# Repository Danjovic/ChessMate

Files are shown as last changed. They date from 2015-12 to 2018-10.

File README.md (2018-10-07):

# ChessMate

The ChessMate is an AVR ATmega328P running at 25 MHz with chess Engine based on recursive negamax search micro-Max 4.8 by [H.G. Muller]
The hash table was removed by [Andre Adrian].

Our contribution are the following features:
- Included [Threefold repetition rule] using Compact Chess Representation of history boards ([C.C.R.]), we made it valid 
for the last 15 boards with 32 bytes per board; so the history boards occupies 480 bytes of RAM.
- Included the [Fifty-move rule] check from [fairy-Max].

Processing Speed:
For instance, the 32-bit test version of Rybka on AMD 64-bit CPU running on 2.4Ghz achieves 104 Knps (thousands of nodes 
per second); refer to [C.C.R.].

The ATmega328P ChessMate at 25 MHz approach, can reach ~1.3 Knps (1298.1 nodes/s).

A node refers to a branch of play the computer investigated. 

[H.G. Muller]: <http://home.hccnet.nl/h.g.muller/max-src2.html>
[Andre Adrian]: <http://www.andreadrian.de/schach/#Selbstbau_Schachcomputer_SHAH>
[C.C.R.]: <http://www.doiserbia.nb.rs/img/doi/0354-0243/2012/0354-02431200011V.pdf>
[fairy-Max]: <http://home.hccnet.nl/h.g.muller/CVfairy.html>
[Demo Video]: <https://youtu.be/5uhqcVmfm20>
[Hackaday Entry]: <https://hackaday.io/project/8705-chess-mate>
[Threefold repetition rule]: <https://en.wikipedia.org/wiki/Threefold_repetition>
[Fifty-move rule]: <https://en.wikipedia.org/wiki/Fifty-move_rule>

> First release at 15-Feb-2016

How to play:
Initially, it should appear "PLAY" at the display
- Press and hold "NEW" + the number of level
- Enter your 4 digit move then press "ENTER"
- Wait for lily thinking (it will be displayed blinking dots)
- The lily move will be displayed just after the thinking
- If you entered an erroneous digit; press "CLR", short press, to delete one digit
- If you want to delete all digits entered, press and hold "CLR"

See the [Demo Video] and the [Hackaday Entry]

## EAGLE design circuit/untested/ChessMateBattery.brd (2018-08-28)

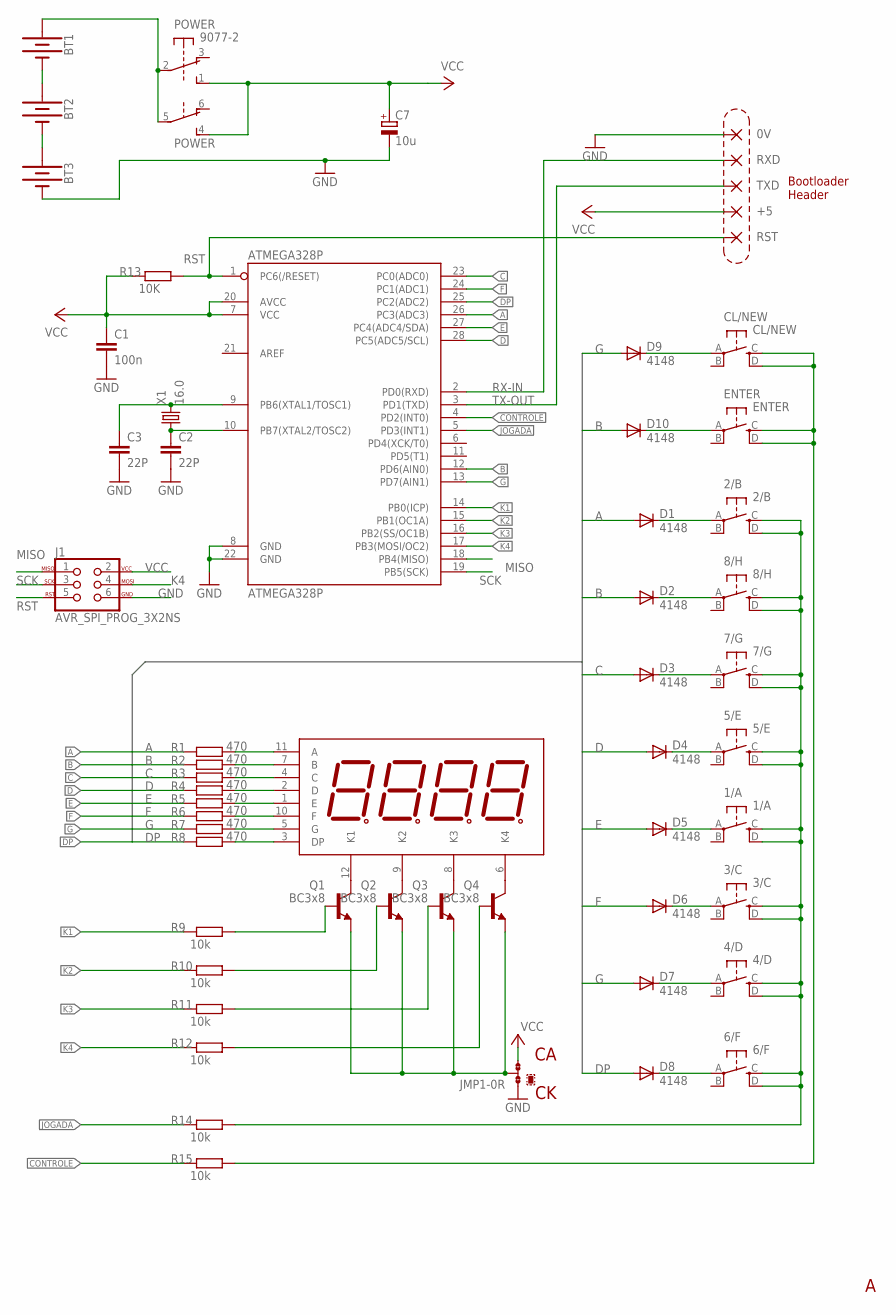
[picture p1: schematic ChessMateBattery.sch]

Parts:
0V: 2,15/1,0
1/A: 1/A; TACT_SW
2/B: 2/B; TACT_SW
3/C: 3/C; TACT_SW
4/D: 4/D; TACT_SW
5/E: 5/E; TACT_SW
6/F: 6/F; TACT_SW
7/G: 7/G; TACT_SW
8/H: 8/H; TACT_SW
+5: 2,15/1,0
ATMEGA328P: ATMEGA328P; DIL28-3
BT1, BT2, BT3: BATTERY-AAA_KIT; BATTERY-AAA-KIT
C1: 100n; C050-024X044L
C2, C3: 22P; C025-024X044L
C7: 10u; TT2D7L
CL/NEW: CL/NEW; TACT_SW
D1, D2, D3, D4, D5, D6, D7, D8, D9, D10: 4148; DO35-7
DISPLAY: 4_DIGIT-TOF3461BH-N; TOF3461BH-N
ENTER: ENTER; TACT_SW
J1: AVR_SPI_PROG_3X2NS; 2X3-NS
JMP1: 0R-JUMPA; A0R-JMP
POWER: 9077-2
Q1, Q2, Q3, Q4: BC3x8; TO92-EBC
R1, R2, R3, R4, R5, R6, R7, R8: 470; 0204/7L
R9, R10, R11, R12, R14, R15: 10k; 0204/7L
R13: 10K; 0204/5L
RST: 2,15/1,0
RXD: 2,15/1,0
TXD: 2,15/1,0
X1: 16.0; HC49/SL

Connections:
A: ATMEGA328P.26 (PC3(ADC3)), D1.A, R1.1
B: ATMEGA328P.12 (PD6(AIN0)), D2.A, D10.A, R2.1
C: ATMEGA328P.23 (PC0(ADC0)), D3.A, R3.1
CONTROLE: ATMEGA328P.4 (PD2(INT0)), R15.1
CONTROLE_: CL/NEW.C (S), CL/NEW.D (S1), ENTER.C (S), ENTER.D (S1), R15.2
D: ATMEGA328P.28 (PC5(ADC5/SCL)), D4.A, R4.1
DP: ATMEGA328P.25 (PC2(ADC2)), D8.A, R8.1
E: ATMEGA328P.27 (PC4(ADC4/SDA)), D5.A, R5.1
F: ATMEGA328P.24 (PC1(ADC1)), D6.A, R6.1
G: ATMEGA328P.13 (PD7(AIN1)), D7.A, D9.A, R7.1
GND: 0V.1, ATMEGA328P.8 (GND), ATMEGA328P.22 (GND), BT3.GND@1 (-), C1.2, C2.2, C3.2, C7.-, J1.6, JMP1.1
JOGADA: ATMEGA328P.5 (PD3(INT1)), R14.1
JOGADA_C: 1/A.C (S), 1/A.D (S1), 2/B.C (S), 2/B.D (S1), 3/C.C (S), 3/C.D (S1), 4/D.C (S), 4/D.D (S1), 5/E.C (S), 5/E.D (S1), 6/F.C (S), 6/F.D (S1), 7/G.C (S), 7/G.D (S1), 8/H.C (S), 8/H.D (S1), R14.2
K1: ATMEGA328P.14 (PB0(ICP)), R9.1
K2: ATMEGA328P.15 (PB1(OC1A)), R10.1
K3: ATMEGA328P.16 (PB2(SS/OC1B)), R11.1
K4: ATMEGA328P.17 (PB3(MOSI/OC2)), J1.4, R12.1
MISO: ATMEGA328P.18 (PB4(MISO)), J1.1
unnamed: DISPLAY.11 (A), R1.2
unnamed: DISPLAY.7 (B), R2.2
unnamed: DISPLAY.4 (C), R3.2
unnamed: DISPLAY.2 (D), R4.2
unnamed: DISPLAY.1 (E), R5.2
unnamed: DISPLAY.10 (F), R6.2
unnamed: DISPLAY.5 (G), R7.2
unnamed: DISPLAY.3 (DP), R8.2
unnamed: Q1.B, R9.2
unnamed: Q2.B, R10.2
unnamed: Q3.B, R11.2
unnamed: Q4.B, R12.2
unnamed: DISPLAY.12 (K1), Q1.C
unnamed: DISPLAY.9 (K2), Q2.C
unnamed: DISPLAY.8 (K3), Q3.C
unnamed: DISPLAY.6 (K4), Q4.C
unnamed: ATMEGA328P.9 (PB6(XTAL1/TOSC1)), C3.1, X1.2
unnamed: ATMEGA328P.10 (PB7(XTAL2/TOSC2)), C2.1, X1.1
unnamed: BT1.PWR@1 (+), POWER.2, POWER.5
unnamed: CL/NEW.A, D9.C
unnamed: D10.C, ENTER.A
unnamed: 2/B.A, D1.C
unnamed: 8/H.A, D2.C
unnamed: 5/E.A, D4.C
unnamed: 1/A.A, D5.C
unnamed: 3/C.A, D6.C
unnamed: 4/D.A, D7.C
unnamed: 6/F.A, D8.C
unnamed: 7/G.A, D3.C
unnamed: BT1.GND@1 (-), BT2.PWR@1 (+)
unnamed: BT2.GND@1 (-), BT3.PWR@1 (+)
unnamed: JMP1.2, Q1.E, Q2.E, Q3.E, Q4.E
RST: ATMEGA328P.1 (PC6(/RESET)), J1.5, R13.2, RST.1
RX-IN: ATMEGA328P.2 (PD0(RXD)), RXD.1
SCK: ATMEGA328P.19 (PB5(SCK)), J1.3
TX-OUT: ATMEGA328P.3 (PD1(TXD)), TXD.1
VCC: +5.1, ATMEGA328P.7 (VCC), ATMEGA328P.20 (AVCC), C1.1, C7.+, J1.2, JMP1.3, POWER.1 (S), POWER.4 (S), R13.1

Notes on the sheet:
Bootloader Header

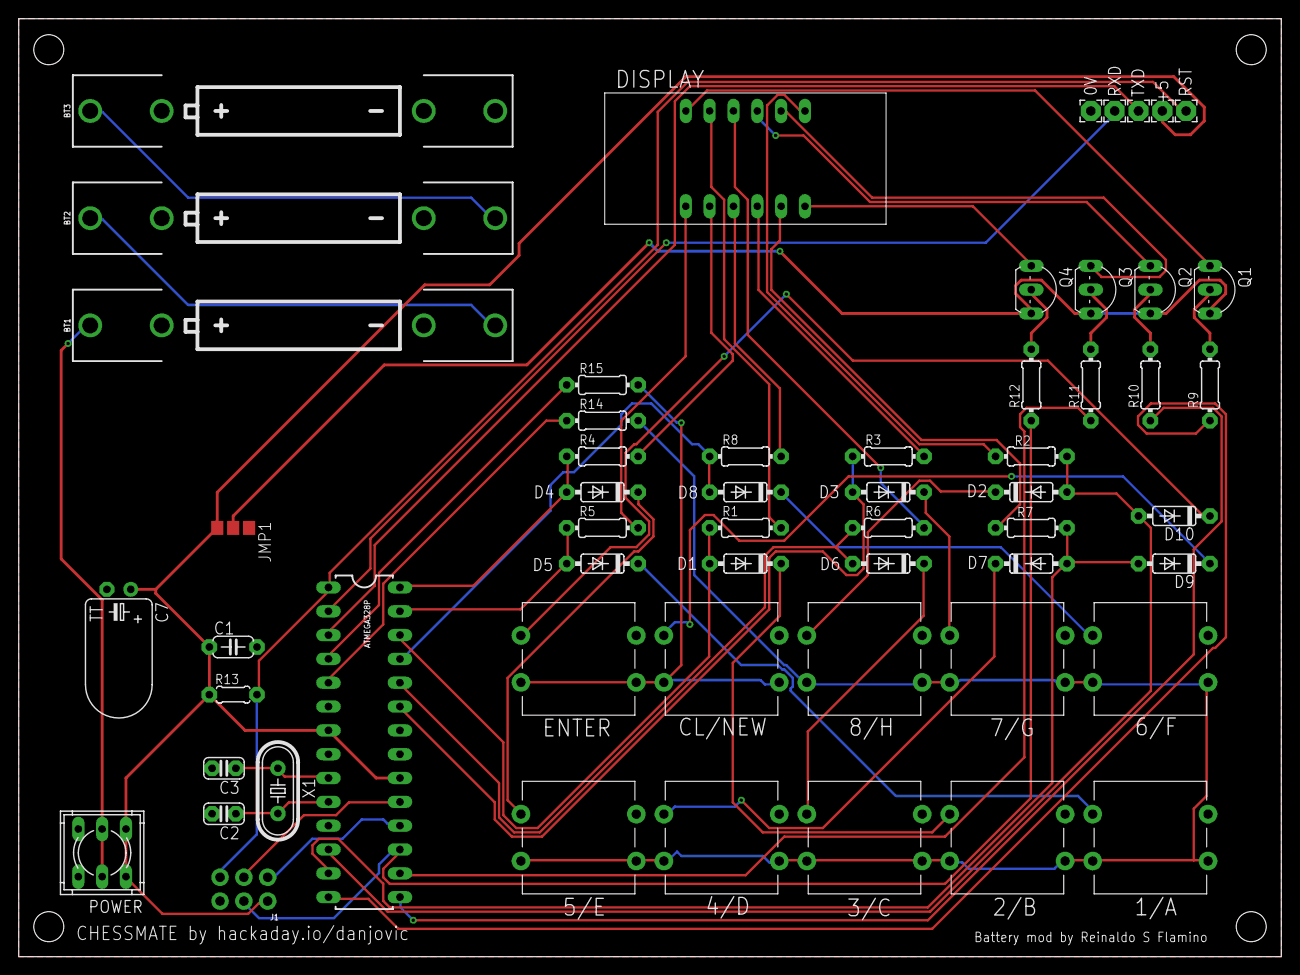
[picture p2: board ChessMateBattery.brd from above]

Board: 2 copper layers, 134.6 x 100.0 mm, 57 parts (0 on the bottom side), 55 nets.

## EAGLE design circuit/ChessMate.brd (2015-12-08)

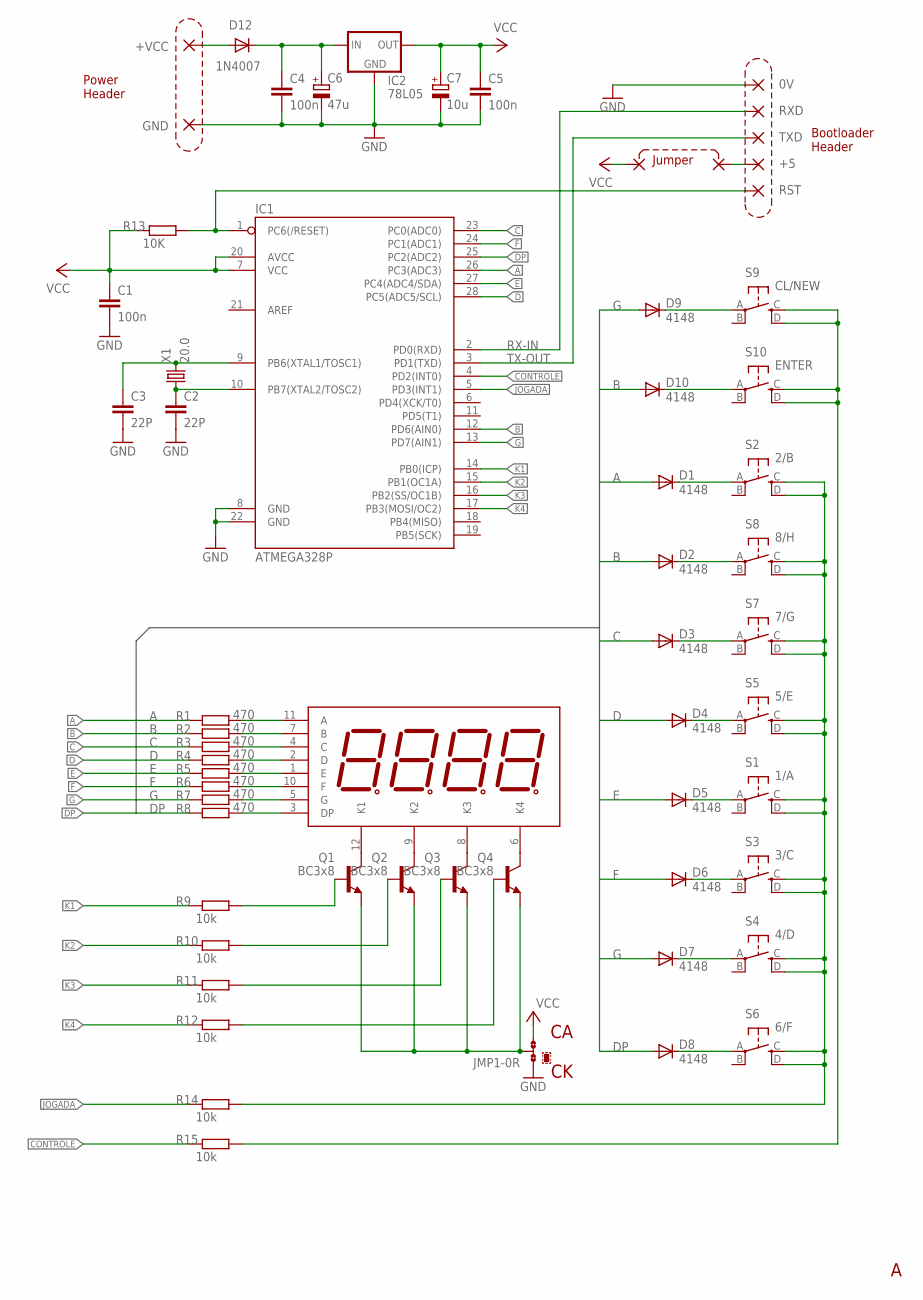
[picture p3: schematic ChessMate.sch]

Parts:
0V: 2,15/1,0
+5: 2,15/1,0
+VCC: 2,15/1,0
C1, C4, C5: 100n; C050-024X044L
C2, C3: 22P; C025-024X044L
C6: 47u; TT2D7L
C7: 10u; TT2D7L
D1, D2, D3, D4, D5, D6, D7, D8, D9, D10: 4148; DO35-7
D12: 1N4007; DO41-7.6L
GND: 2,15/1,0
IC1: ATMEGA328P; DIL28-3
IC2: 78L05; TO92_
JMP1: 0R-JUMPA; A0R-JMP
LD1: 4_DIGIT-TOF3461BH-N; TOF3461BH-N
PAD1, PAD2: 1,6/0,8
Q1, Q2, Q3, Q4: BC3x8; TO92-EBC
R1, R2, R3, R4, R5, R6, R7, R8: 470; 0204/7L
R9, R10, R11, R12, R14, R15: 10k; 0204/7L
R13: 10K; 0204/5L
RST: 2,15/1,0
RXD: 2,15/1,0
S1: 1/A; TACT_SW
S2: 2/B; TACT_SW
S3: 3/C; TACT_SW
S4: 4/D; TACT_SW
S5: 5/E; TACT_SW
S6: 6/F; TACT_SW
S7: 7/G; TACT_SW
S8: 8/H; TACT_SW
S9: CL/NEW; TACT_SW
S10: ENTER; TACT_SW
TXD: 2,15/1,0
X1: 20.0; HC49/SL

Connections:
A: D1.A, IC1.26 (PC3(ADC3)), R1.1
B: D2.A, D10.A, IC1.12 (PD6(AIN0)), R2.1
C: D3.A, IC1.23 (PC0(ADC0)), R3.1
CONTROLE: IC1.4 (PD2(INT0)), R15.1
CONTROLE_: R15.2, S9.C (S), S9.D (S1), S10.C (S), S10.D (S1)
D: D4.A, IC1.28 (PC5(ADC5/SCL)), R4.1
DP: D8.A, IC1.25 (PC2(ADC2)), R8.1
E: D5.A, IC1.27 (PC4(ADC4/SDA)), R5.1
F: D6.A, IC1.24 (PC1(ADC1)), R6.1
G: D7.A, D9.A, IC1.13 (PD7(AIN1)), R7.1
GND: 0V.1, C1.2, C2.2, C3.2, C4.2, C5.2, C6.-, C7.-, GND.1, IC1.8 (GND), IC1.22 (GND), IC2.2 (GND), JMP1.1
JOGADA: IC1.5 (PD3(INT1)), R14.1
JOGADA_C: R14.2, S1.C (S), S1.D (S1), S2.C (S), S2.D (S1), S3.C (S), S3.D (S1), S4.C (S), S4.D (S1), S5.C (S), S5.D (S1), S6.C (S), S6.D (S1), S7.C (S), S7.D (S1), S8.C (S), S8.D (S1)
K1: IC1.14 (PB0(ICP)), R9.1
K2: IC1.15 (PB1(OC1A)), R10.1
K3: IC1.16 (PB2(SS/OC1B)), R11.1
K4: IC1.17 (PB3(MOSI/OC2)), R12.1
unnamed: LD1.11 (A), R1.2
unnamed: LD1.7 (B), R2.2
unnamed: LD1.4 (C), R3.2
unnamed: LD1.2 (D), R4.2
unnamed: LD1.1 (E), R5.2
unnamed: LD1.10 (F), R6.2
unnamed: LD1.5 (G), R7.2
unnamed: LD1.3 (DP), R8.2
unnamed: Q1.B, R9.2
unnamed: Q2.B, R10.2
unnamed: Q3.B, R11.2
unnamed: Q4.B, R12.2
unnamed: LD1.12 (K1), Q1.C
unnamed: LD1.9 (K2), Q2.C
unnamed: LD1.8 (K3), Q3.C
unnamed: LD1.6 (K4), Q4.C
unnamed: IC1.1 (PC6(/RESET)), R13.2, RST.1
unnamed: C3.1, IC1.9 (PB6(XTAL1/TOSC1)), X1.2
unnamed: C2.1, IC1.10 (PB7(XTAL2/TOSC2)), X1.1
unnamed: +VCC.1, D12.A
unnamed: D9.C, S9.A
unnamed: D10.C, S10.A
unnamed: D1.C, S2.A
unnamed: D2.C, S8.A
unnamed: D4.C, S5.A
unnamed: D5.C, S1.A
unnamed: D6.C, S3.A
unnamed: D7.C, S4.A
unnamed: D8.C, S6.A
unnamed: D3.C, S7.A
unnamed: +5.1, PAD2.1
unnamed: C4.1, C6.+, D12.C, IC2.3 (IN)
unnamed: JMP1.2, Q1.E, Q2.E, Q3.E, Q4.E
RX-IN: IC1.2 (PD0(RXD)), RXD.1
TX-OUT: IC1.3 (PD1(TXD)), TXD.1
VCC: C1.1, C5.1, C7.+, IC1.7 (VCC), IC1.20 (AVCC), IC2.1 (OUT), JMP1.3, PAD1.1, R13.1

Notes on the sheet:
Bootloader Header
Power Header
Jumper

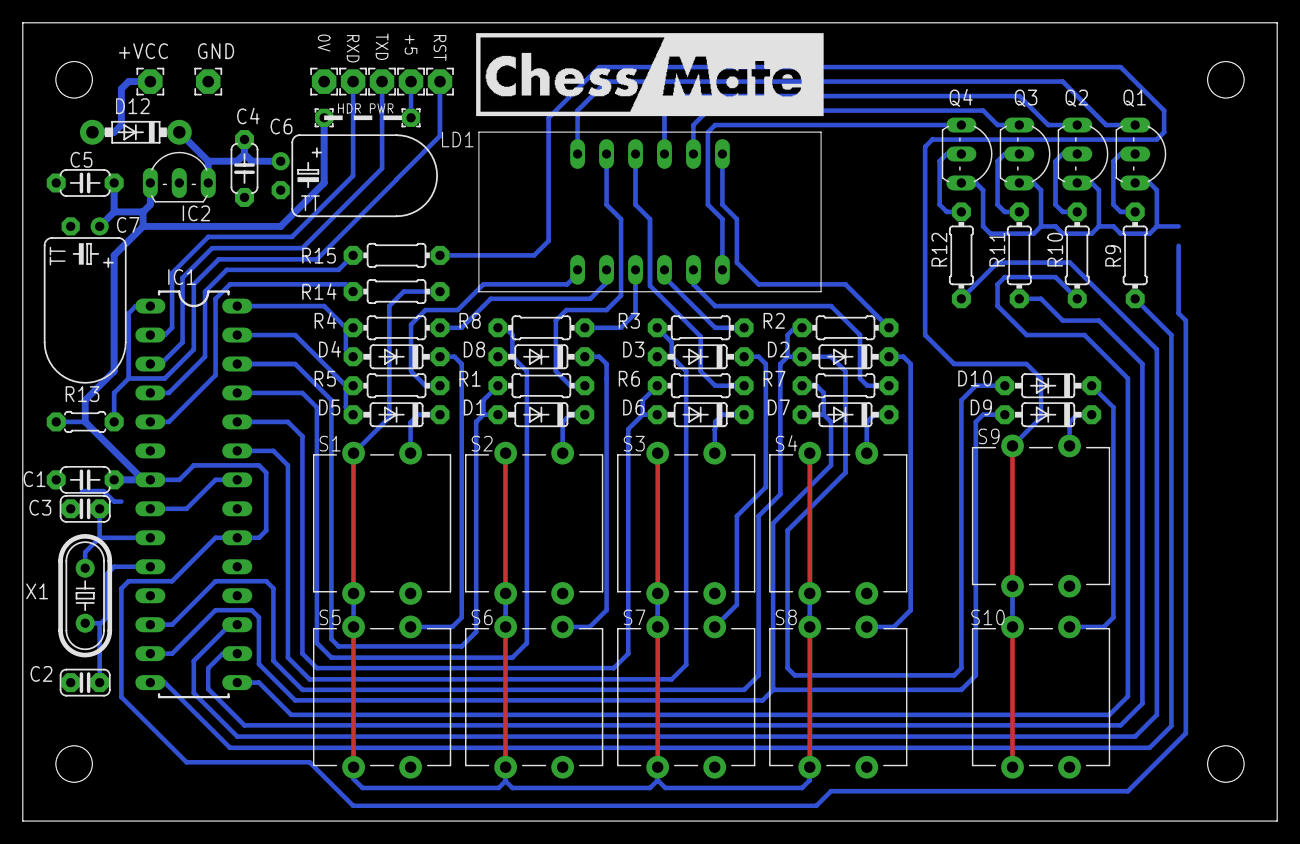
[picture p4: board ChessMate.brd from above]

Board: 2 copper layers, 110.0 x 70.0 mm, 62 parts (1 on the bottom side), 53 nets.

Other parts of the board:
U$1: PB108_SMALL_HOLES

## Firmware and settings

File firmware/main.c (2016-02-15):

//
////////////////////////////////////////////////////////////////////////////////
//                  ___ _              __  __      _                          //
//                 / __| |_  ___ _____|  \/  |__ _| |_ ___                    //
//                | (__| ' \/ -_|_-<_-< |\/| / _` |  _/ -_)                   //
//                 \___|_||_\___/__/__/_|  |_\__,_|\__\___|                   //
//                                                                            //
//                                                                            //
//       __/)         Microcontroller based Chess Computer                    //
//    .-(__(=:                                                                //
// |\ |    \)                                                                 //
// \ ||       Authors: Daniel Jose Viana - danjovic@hotmail.com               //
//  \||                Reinaldo de Sales Flamino - reinaldosflamino@gmail.com //
//ejm\|                                                                       //
// 97 |                   Version 0.1 - 15 Feb 2016		              //
////////////////////////////////////////////////////////////////////////////////
// Titles in ASCII art by Patrick Gillespi http://patorjk.com/software/taag/  //
// Lily ASCII art by ejm                                                      //
////////////////////////////////////////////////////////////////////////////////
#ifndef F_CPU 
#define F_CPU 25000000
#endif


////////////////////////////////////////////////////////////////////////////////
// required headers
#include <avr/io.h>
#include <stdio.h>
#include <avr/wdt.h>
#include <avr/interrupt.h>
#include <util/delay.h>
#include <avr/pgmspace.h>
#include <string.h>
#include "lily.h"
#include "uart.h"

#define USART_BAUDRATE 19200
////////////////////////////////////////////////////////////////////////////////
// Definitions
#include "7seg_definitions.h"




////////////////////////////////////////////////////////////////////////////////
// Constants in ROM
const PROGMEM int difficult_level[8] = {10,100,200,500,700,1000,1500,2000};
const PROGMEM uint8_t ascii_char[16] = {'1','2','3','4','5','6','7','8','a','b','c','d','e','f','g','h'};
const PROGMEM uint8_t     digits[16] = {_1, _2, _3, _4, _5, _6, _7, _8, _A, _B, _C, _D, _E, _F, _G, _H};

///////////////////////////////////////////////////////////////////////////////
// Variables

//static uint8_t Display[4] = { _SPC, _SPC, _SPC, _SPC };   // blank display
static uint8_t KeyStatus = 0;                             // no key pressed

//set stream pointer
FILE usart0_str = FDEV_SETUP_STREAM(USART0SendByte, USART0ReceiveByte, _FDEV_SETUP_RW);

////////////////////////////////////////////////////////////////////////////////
// Functions

////////////////////////////////////////////////////////////////////////////////
//
void Initialize_Hardware (void) {
	DDRB=0x0f;  // bits 4..0 as outputs
	PORTB=0x0f; // All segments off
	
	DDRD = 0xc0; // bits 7..6 as outuputs
	PORTD = 0xfC; // All segments off, pullups on pins 2 and 3 and unused
	
	DDRC = 0x3f; // bits 5..0 as outputs
	PORTC = 0x3f; // All segments off
	
	// Configure timer
	TCCR2B = (1<<CS20) | (1<<CS21) | (1<<CS22);  // Timer 2 prescaler 1024
	// bits 7 turn at a rate of 191Hz (change once at each 5,2ms)

}




////////////////////////////////////////////////////////////////////////////////
// Refresh Display and scan keyboard
// return value in key status: bit  7 6 5 4 3 2 1 0
// NEW event -----------------------+ | | | | \   /
// CLR long=1/short=0 ----------------+ | | |  \ /
// CLR event----------------------------+ | |   V
// ENTER event----------------------------+ |   |
// Key[1-8] event---------------------------+   |
// Key Pressed (1..8)---------------------------+

#define NEW_EVENT   7
#define CLR_LONG    6
#define CLR_EVENT   5
#define ENTER_EVENT 4
#define KEY18_EVENT 3
#define treshold_long_press 228 // ~600ms
#define treshold_short_press 28 //



#define _MOVE_PIN 3
#define _CONTROL_PIN 2

#define MOVE ((PIND & (1<<_MOVE_PIN))==0)

#define CONTROL ((PIND & (1<<_CONTROL_PIN))==0)




void Clear_Display(void) {

	Display[0]= _SPC;     // Clear display
	Display[1]= _SPC;
	Display[2]= _SPC;
	Display[3]= _SPC;
	
	c[0]=32;              // Clear move vector (fill with spaces)
	c[1]=32;
	c[2]=32;
	c[3]=32;
	c[4]=10;

}




////////////////////////////////////////////////////////////////////////////////
//
void Refresh_display (void) {

	uint8_t temp,Keys18;
	
	static uint8_t last_key=0;
	static uint8_t last_digit=0;
	static uint8_t key18_ticks = 0;
	static uint8_t key_clr_ticks  = 0;
	static uint8_t key_ent_ticks  = 0;

	uint8_t digit_now = (TCNT2 >>6 ) & 0x03; // switch each digit ~10,5ms


	// check if it's time to change the segment and scan the keyboard

	if (digit_now != last_digit) { // will occur once at each 2,6 ms
		last_digit = digit_now;
		
		
		/////////////////////////////////////////////////////////////////////////
		// change pins to read keyboard
		
		PORTB=0x0f; // All segments off
		
		PORTD |=0xfc; // Pins B, G in high, pullups on pins
		PORTC |=0x3f; // pins D, F, Dp, A, E, D in high

		
		
		/////////////////////////////////////////////////////////////////////////
		// Process CLR/NEW KEY
		PORTD &= ~(1<<7);   // Drop line and wait for settle down
		asm ("nop");
		asm ("nop");
		asm ("nop");
		
		Keys18=MOVE ;  // save state of move button for this line
		
		
		if (CONTROL) { // count how many cycles (2,6ms each) button CLR/NEW remain pressed
			if ( key_clr_ticks <255 ) {// advance and saturate
				key_clr_ticks++;
			}
			KeyStatus &= ~(1<<CLR_EVENT);  // CLR not pressed;
			} else {                           // button CLR is released
			temp=key_clr_ticks;
			key_clr_ticks=0;
			KeyStatus &= ~(1<<CLR_EVENT | 1<<CLR_LONG); // by default no event if press under treshold
			if (temp > treshold_long_press) KeyStatus|=(1<<CLR_EVENT | 1<<CLR_LONG) ;
			if (temp > treshold_short_press) KeyStatus|=(1<<CLR_EVENT) ;
		}
		PORTD |= (1<<7);   // Raise line pin again
		
		
		
		/////////////////////////////////////////////////////////////////////////
		// Process ENTER Key
		PORTD &= ~(1<<6);   // Drop line and wait for settle down
		asm ("nop");
		asm ("nop");
		asm ("nop");
		
		Keys18=(Keys18<<1)| MOVE ;  // save state of move button for this line
		
		if (CONTROL) { // count how many cycles (2,6ms each) button CLR/NEW remain pressed
			if ( key_ent_ticks <255 ) {// advance and saturate
				key_ent_ticks++;
			}
			KeyStatus &= ~(1<<ENTER_EVENT);  // ENTER not pressed;
			} else {                           // button ENTER is released
			temp=key_ent_ticks;
			key_ent_ticks=0;
			KeyStatus &= ~(1<<ENTER_EVENT); // by default no event if press under treshold
			if (temp > treshold_short_press) KeyStatus|=(1<<ENTER_EVENT) ;
		}
		PORTD |= (1<<6);   // Raise line pin again


		/////////////////////////////////////////////////////////////////////////
		// Process Keys 1-8
		PORTC &= ~(1<<5);   // Drop line and wait for settle down
		asm ("nop");
		asm ("nop");
		asm ("nop");
		Keys18=(Keys18<<1) | MOVE ;  // save state of move button for this line
		PORTC |= (1<<5);   // Raise line pin again
		
		PORTC &= ~(1<<4);   // Drop line and wait for settle down
		asm ("nop");
		asm ("nop");
		asm ("nop");
		Keys18=(Keys18<<1) | MOVE ;  // save state of move button for this line
		PORTC |= (1<<4);   // Raise line pin again
		
		PORTC &= ~(1<<3);   // Drop line and wait for settle down
		asm ("nop");
		asm ("nop");
		asm ("nop");
		Keys18=(Keys18<<1) | MOVE ;  // save state of move button for this line
		PORTC |= (1<<3);   // Raise line pin again
		
		PORTC &= ~(1<<2);   // Drop line and wait for settle down
		asm ("nop");
		asm ("nop");
		asm ("nop");
		Keys18=(Keys18<<1) | MOVE ;  // save state of move button for this line
		PORTC |= (1<<2);   // Raise line pin again
		
		PORTC &= ~(1<<1);   // Drop line and wait for settle down
		asm ("nop");
		asm ("nop");
		asm ("nop");
		Keys18=(Keys18<<1) | MOVE ;  // save state of move button for this line
		PORTC |= (1<<1);   // Raise line pin again
		
		PORTC &= ~(1<<0);   // Drop line and wait for settle down
		asm ("nop");
		asm ("nop");
		asm ("nop");
		Keys18=(Keys18<<1) | MOVE ;  // save state of move button for this line
		PORTC |= (1<<0);   // Raise line pin again
		

		
		if (Keys18) { // count how many any button remain pressed
			if ( key18_ticks <255 ) {// advance and saturate
				key18_ticks++;
			}
			last_key=Keys18;             // save button pressed

			KeyStatus &= ~(1<<KEY18_EVENT);  // No key 1-8 not pressed;
			} else {                           // button ENTER is released
			temp=key18_ticks;
			key18_ticks=0;
			KeyStatus &= ~(1<<KEY18_EVENT); // by default no event if press under treshold
			if (temp > treshold_short_press) {
				KeyStatus|=(1<<KEY18_EVENT) ;    // Set Key Event Flag
				
				
				KeyStatus &= 0b11111000;         // Clear key number
				
				switch (last_key) {
					case 0b00010000: KeyStatus |= 0;   // Key 1
					break;
					case 0b00001000: KeyStatus |= 1;   // Key 2
					break;
					case 0b00000010: KeyStatus |= 2;   // Key 3
					break;
					case 0b10000000: KeyStatus |= 3;   // Key 4
					break;
					case 0b00100000: KeyStatus |= 4;   // Key 5
					break;
					case 0b00000100: KeyStatus |= 5;   // Key 6
					break;
					case 0b00000001: KeyStatus |= 6;   // Key 7
					break;
					case 0b01000000: KeyStatus |= 7;   // Key 8
					break;
					
					default:         KeyStatus &= ~(1<<KEY18_EVENT); //// more than one key pressed simultaneously
					
					
				}
				
				// Process NEW event
				if ((KeyStatus & (1<<KEY18_EVENT)) && (key_clr_ticks > treshold_long_press))
				KeyStatus |= (1<<NEW_EVENT);
				else (KeyStatus &= ~(1<<NEW_EVENT));

			} else last_key=0;

		}
		
		
		
		/////////////////////////////////////////////////////////////////////////
		// Update Display
		//DDRD = 0xc0; // bits 7..6 as outuputs again
		//DDRC = 0x3f; // bits 5..0 as outputs again
		
		PORTB=0xff;
		PORTC = ~Display[digit_now] & 0x3f;
		PORTD |= 0xc0;
		PORTD &= (~Display[digit_now] | 0x3f );
		
		switch (digit_now) {           // Enable current display anode
			case 0:  PORTB=0xfe; break;
			case 1:  PORTB=0xfd; break;
			case 2:  PORTB=0xfb; break;
			case 3:  PORTB=0xf7; break;

		}
	}

}

//
////////////////////////////////////////////////////////////////////////////////




// Print Board at UART
uint8_t printBoard(void) {
	
	printf_P(PSTR("\nChessMate\n\n"));
	
	int NN=-1;
	while(++NN<121) {
		printf("%c",NN&8&&(NN+=7)?10:".?+nkbrq?*?NKBRQ"[b[NN]&15]); /* print board */
	}
	
	printf_P(PSTR("\nCHECKMATE	Legal?	Last	Depth	Score	(Wht=16)\n"));
	printf("%d		%d		%d		%d	%d\n",CHECKMATE,LegalMove,Depth,SCORE,k);
	return 0;
}

void setDisplay() {


			switch (CHECKMATE) {	// Display message according to Check
				case _White_Wins:
				Display[0]= _W;
				Display[1]= _H;
				Display[2]= _I;
				Display[3]= _T;
				break;
				case _Black_Wins:
				Display[0]= _B;
				Display[1]= _L;
				Display[2]= _A;
				Display[3]= _C;
				break;
				case _Stale_Mate:
				Display[0]= _S;
				Display[1]= _T;
				Display[2]= _A;
				Display[3]= _L;
				break;
				case _50th_Move:
				Display[0]= _5;
				Display[1]= _0;
				Display[2]= _T;
				Display[3]= _H;
				break;
				case _Threefold:
				Display[0]= _3;
				Display[1]= _F;
				Display[2]= _L;
				Display[3]= _D;
				break;
				default:
				Display[0]= _E;
				Display[1]= _R;
				Display[2]= _R;
				Display[3]= _O;
			};
}

////////////////////////////////////////////////////////////////////////////////
//  __  __      _        ___             _   _
// |  \/  |__ _(_)_ _   | __|  _ _ _  __| |_(_)___ _ _
// | |\/| / _` | | ' \  | _| || | ' \/ _|  _| / _ \ ' \
// |_|  |_\__,_|_|_||_| |_| \_,_|_||_\__|\__|_\___/_||_|
//


int main( void)
{
	uint8_t cm=0 ; // save check mate state
	uint8_t i=0;
	uint8_t digit_now=0;
	uint8_t First_key=0;
	LilyStatus LilyState = _Startup_Screen;
	
	
	wdt_disable(); // no watchdog
	Initialize_Hardware ();

	///////////////// init USART
	USART0Init();
	stdout = &usart0_str;
	stdin  = &usart0_str;
	printf_P(PSTR("\nLets Play"));
	////////////////////////////////	

	// Start the show!
	
	for (;;) {
		
		switch (LilyState) {
			
			///////////////////////////////////////////////////////////////////////
			case _Startup_Screen:
			Display[0] = _P;   // Now is fixed but can be animated
			Display[1] = _L;   // but now I am simply overwriting
			Display[2] = _A;
			Display[3] = _Y;
			
			i=KeyStatus;                             // Save Key Events
			
			if ( KeyStatus & (1<<NEW_EVENT) ) {      // Check for a NEW event
				KeyStatus=0;                         // If that's the case start a new game
				LilyState = _New_Game;
				RL = pgm_read_word(&difficult_level[(i & 0x07)] );      // Configure recursion (difficulty) level
			}
			break;
			
			
			///////////////////////////////////////////////////////////////////////
			case _New_Game:
			Display[0] = _D;        // Update display. This message can be animated
			Display[1] = _I;        // but now I am simply overwriting
			Display[2] = _F;
			Display[3]=pgm_read_byte(digits+ (i & 0x07) ); // show difficulty level
			
			//if ((KeyStatus & (1<<KEY18_EVENT)) | (KeyStatus & (1<<ENTER_EVENT))) {
				if ((KeyStatus & (1<<KEY18_EVENT)) ) {
				Clear_Display();
				digit_now=0;          // Set position as the first digit
				
				initlily();

				//if (KeyStatus & (1<<ENTER_EVENT)) {
				//	LilyState=_Lily_Move;
					//k=BLACK;//today
					//	printf_P(PSTR("\nLily first"));
				//	} else {
				//	LilyState=_Human_Move;
					//k=WHITE;//today
					//	printf_P(PSTR("\nHuman first"));
				//}
				
				LilyState = _Human_Move;
				KeyStatus=0;
			}
			break;
			
			///////////////////////////////////////////////////////////////////////
			case _Human_Move:
			// Check if NEW was pressed
			i=KeyStatus;                             // Save Key Events
			if ( KeyStatus & (1<<NEW_EVENT) ) {      // Check for a NEW event
				LilyState = _New_Game;               // If that's the case start a new game
				RL = pgm_read_word(&difficult_level[(i & 0x07)] );      // set difficulty level
				KeyStatus=0;
				break;
			}

			// Check if need to clear the display, e.g. after lily has played
			if (i!=0 && First_key) {
				//printf_P(PSTR("\nYour Move "));
				First_key=0;
				Clear_Display();
				digit_now=0;
			}



			// Check if ENTER was pressed
			if (KeyStatus & (1<<ENTER_EVENT)) {
				
				
				//if ( (c[0]==32) && (RL<2000)) {   // if clear screen with difficulty level 1..4
				if ( (c[0]==97&&c[1]==32 && (RL<difficult_level[4]))) {  //if "A" key + enter pressed 
					c[0]=10;                     // then tell Lily to play for you
				    //printf_P(PSTR("\nLily will play for you "));					
				}
				

				Display[0] = _DP;  
				PORTB=0xff;
				PORTC = ~Display[0] & 0x3f;
				PORTD |= 0xc0;
				PORTD &= (~Display[0] | 0x3f );
				PORTB=0xfe;

				cm=playlily();        // Make Human Move
				
				printBoard();		// Print Board

					// Test for Check mate
					if (cm!=0) {
						//setDisplay();
						//printf_P(PSTR("\nGame Over "));
						LilyState = _Check_Mate;	// Yes, show result
						KeyStatus=0;
						
						break;
					}

				if (!LegalMove) {				// Human move was legal?
					//printf_P(PSTR("\nHuman bad move. "));
					Clear_Display();			// No, clear screen,
					//Display[0]=_DP;
					Display[0] = _E;  
					Display[1] = _R;   
					Display[2] = _R;
					Display[3] = _O;					
					
					
					digit_now=0;         		// set position as the first digit
					//LilyState = _Human_Move;	// and return control to human
					KeyStatus=0;
					First_key=1;
					break;
					}	else {					//Human move was legal
					
						//printf_P(PSTR("\ngood move."));
						
						if (k==WHITE) {
							LilyState = _Human_Move;
							First_key=1;                // for clear display
							KeyStatus=0;
							} else {
							LilyState = _Lily_Move;           // Send your move to Lily
							//c[0]=10;
							KeyStatus=0;
						}

						break;
						

					
				}			
				
			}			

			
			// Check if CLEAR was Long pressed
			if (KeyStatus & (1<<CLR_EVENT) && (KeyStatus & (1<<CLR_LONG)) ) {
				
				Clear_Display();
				digit_now=0;          // Set position as the first digit
				
				KeyStatus=0;
				break;
			}
			
			
			// Check if CLEAR was Short pressed
			if (KeyStatus & (1<<CLR_EVENT) && !(KeyStatus & (1<<CLR_LONG)) ) {
				// clear display and decrement pointer according with position
				
				switch(digit_now & 0x03) {
					case 2:
					case 1: digit_now--;
					case 0:	c[digit_now]=32;
					Display[digit_now]=_SPC;
					break;
					
					case 3:
					if (c[digit_now]==32) {  // if haven't keyed yet on the last position
						digit_now--;          // return to previous position
						Display[digit_now]=_SPC;
						} else {
						c[digit_now]=32;          // otherwise clear current position only
						Display[digit_now]=_SPC;
						break;
					}
				}
				KeyStatus=0;
				break;
			}

			
			// Check if a KEY 1..8 was  pressed
			if (KeyStatus & (1<<KEY18_EVENT) ) {
				i=KeyStatus & 0x07;
				// Fill in c[] and Display[]
				switch(digit_now & 0x03) {
					case 0:
					case 2: c[digit_now]=pgm_read_byte(ascii_char+i+8);
					Display[digit_now]=pgm_read_byte(digits+i+8);
					break;
					case 1:
					case 3: c[digit_now]=pgm_read_byte(ascii_char+i);
					Display[digit_now]=pgm_read_byte(digits+i);
					break;
				}
				if (digit_now<3) digit_now++; // limit to the last digit
				
				KeyStatus=0;
				break;
			}
			
			
			break;
			
			
			///////////////////////////////////////////////////////////////////////
			case _Lily_Move:

			//printf_P(PSTR("\nNow Lily will play."));
			
			c[0]=10;
			
			Display[0] = _DP;  
			PORTB=0xff;
			PORTC = ~Display[0] & 0x3f;
			PORTD |= 0xc0;
			PORTD &= (~Display[0] | 0x3f );
			PORTB=0xfe; 
									
			
			cm=playlily();        // Make Lily Move
			
			//printf_P(PSTR(" Done.\n"));

			printBoard();		// Print Board

			// Check for Check mate
			if (cm!=0) {
				//setDisplay();
				//printf_P(PSTR("\nGame Over "));
				LilyState = _Check_Mate;	// Yes, show result
				KeyStatus=0;
				
				break;
			}
			
				
			// Check for Terminated game (bit 7 is set). In this case playlily returns new difficulty level
			if (cm & 0x80 ) {
				i=cm & 0x07;
				RL = pgm_read_word(&difficult_level[(cm & 0x07)] );  //  Configure recursion (difficulty) level
				LilyState = _New_Game;
				KeyStatus=0;
				break;
				
			}
			
                  
				
				// Must convert from ASCII to code;
				Display[0] = pgm_read_byte( &digits [ ((c[0]-1) & 0x07) + 8 ]); // first is a letter
				Display[1] = pgm_read_byte( &digits [ ((c[1]-1) & 0x07)     ]); // second is a number
				Display[2] = pgm_read_byte( &digits [ ((c[2]-1) & 0x07) + 8 ]); // third is a letter
				Display[3] = pgm_read_byte( &digits [ ((c[3]-1) & 0x07)     ]); // fourth is a number
				Display[3] |= _DP;
				digit_now=0;         		// set position as the first digit
				
				if (k==WHITE) {
					LilyState = _Human_Move;
					First_key=1;                // for clear display
					KeyStatus=0;
				} else {
						LilyState = _Lily_Move;           // Send your move to Lily
						//c[0]=10;
						KeyStatus=0;
				}				
			
			break;
			
			
			///////////////////////////////////////////////////////////////////////
			case _Check_Mate:
			
			setDisplay();
		
			digit_now=0;
			
			// Check if NEW was pressed to restart the game
			i=KeyStatus;                             // Save Key Events
			if ( KeyStatus & (1<<NEW_EVENT) ) {      // Check for a NEW event
				LilyState = _New_Game;               // If that's the case start a new game
				RL = pgm_read_word(&difficult_level[(i & 0x07)] );      // set difficulty level
				KeyStatus=0;
				break;
			}

			break;
			
			///////////////////////////////////////////////////////////////////////
			default:
			
			
			break;
			
			
			
		} // switch
		Refresh_display();
	} ; // for(;;)
}

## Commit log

2015-12-08 First code
    [ChessMate.brd, ChessMate.sch]
2018-08-28 Add files via upload
    battery mod
    [ChessMateBattery_revD.brd, ChessMateBattery_revD.sch]
2018-09-19 chessmate battery mod not working - moved to diff directory
    [ChessMateBattery.brd, ChessMateBattery.sch]

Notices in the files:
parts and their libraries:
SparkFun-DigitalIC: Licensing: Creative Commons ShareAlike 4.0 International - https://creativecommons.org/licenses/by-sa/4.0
